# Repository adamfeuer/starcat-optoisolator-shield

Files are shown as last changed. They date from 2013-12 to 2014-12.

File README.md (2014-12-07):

StarCat Optoisolator Shield
===========================

This is an opto-isolated digital input/output shield for the Arduino Due.

It's good for low-noise synchronization of digital equipment (push-buttons, etc.) with 
an Arduino Due system. The optical isolation enables the connection of otherwise-noisy
external circuits or equipment, preventing ground or power supply noise from affecting 
sensitive ADC measurements. 

Meant for use with the [HackEEG](https://github.com/adamfeuer/hackeeg-shield) 24-bit EEG 
ADC board.

Features
========

* 4 opto-isolated inputs
* 2 opo-isolated outputs
* Screw terminals for connecting external inputs and outputs
* Uses Vishay [ILD213T](http://www.vishay.com/docs/83647/ild205t.pdf) optoisolator IC

License
=======

[Creative Commons By-Attribution ShareAlike 4.0](https://creativecommons.org/licenses/by-sa/4.0/)

Comments
========

If you have questions, comments, or improvements, I would love to know them!

cheers <br>
adam <br>
Adam Feuer <br>
Seattle, WA, USA <br>
adam@adamfeuer.com <br>
http://adamfeuer.com <br>

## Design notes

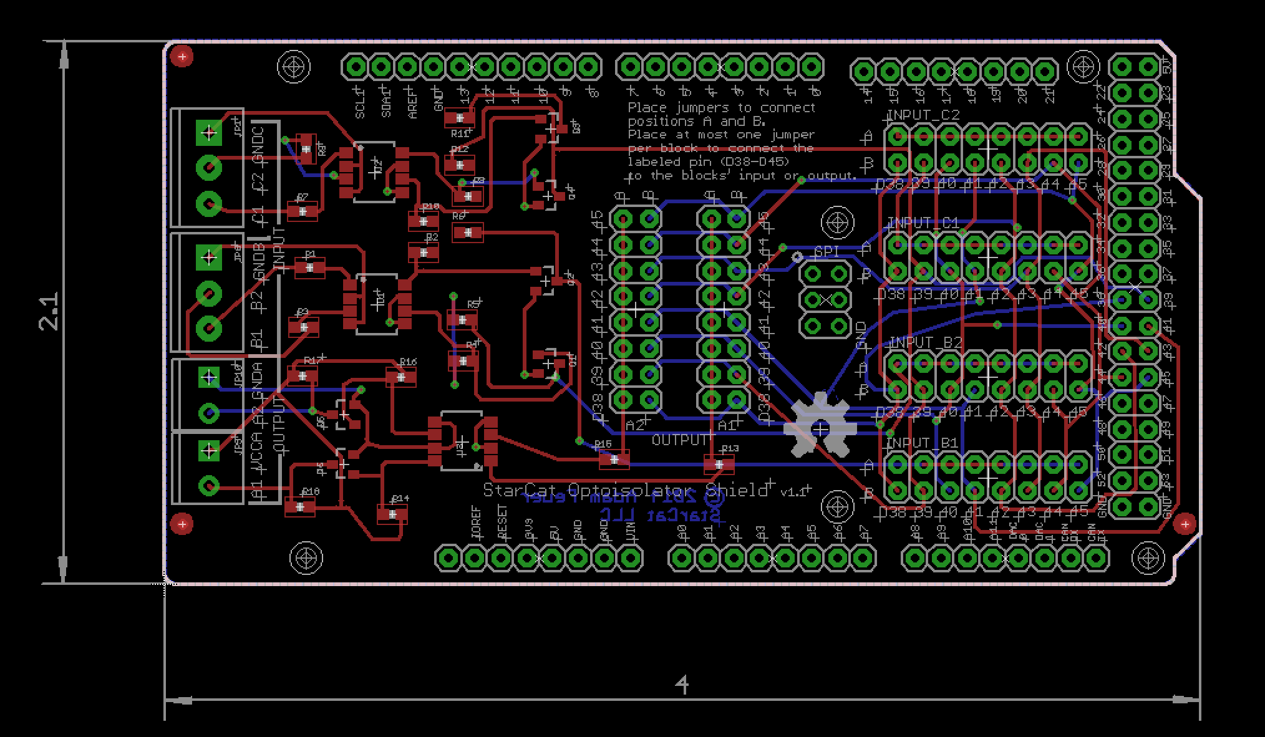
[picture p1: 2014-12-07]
optoisolator-shield.png

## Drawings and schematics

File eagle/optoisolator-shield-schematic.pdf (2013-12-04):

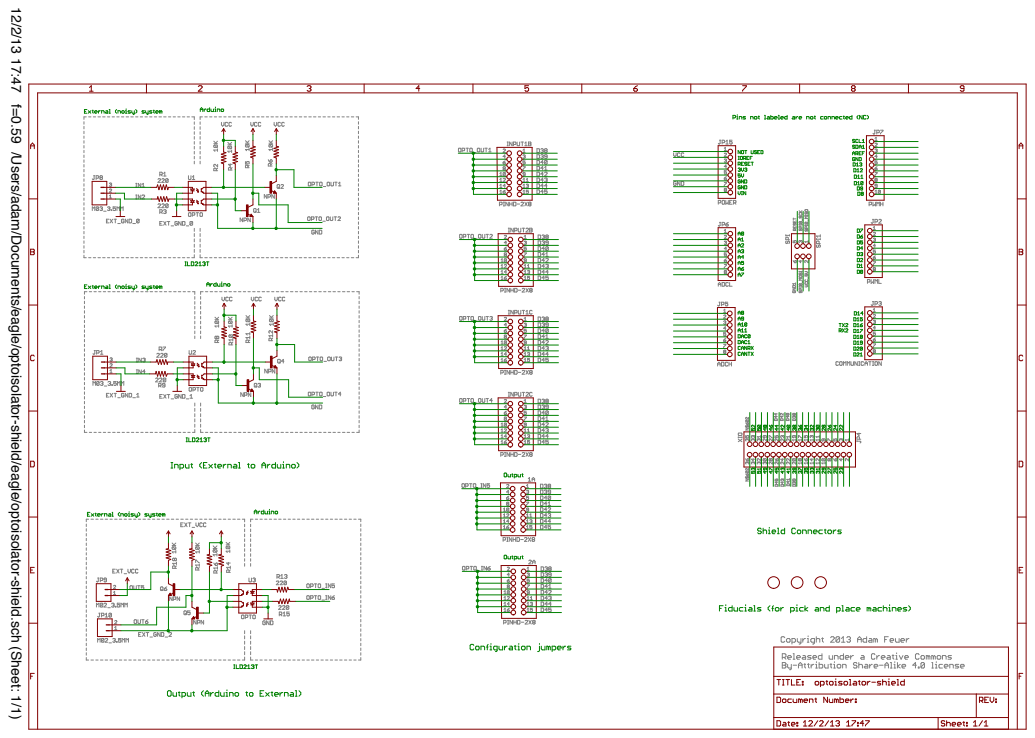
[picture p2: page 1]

12/2/13 17:47 f=0.59 /Users/adam/Documents/eagle/optoisolator-shield/eagle/optoisolator-shield.sch (Sheet: 1/1)

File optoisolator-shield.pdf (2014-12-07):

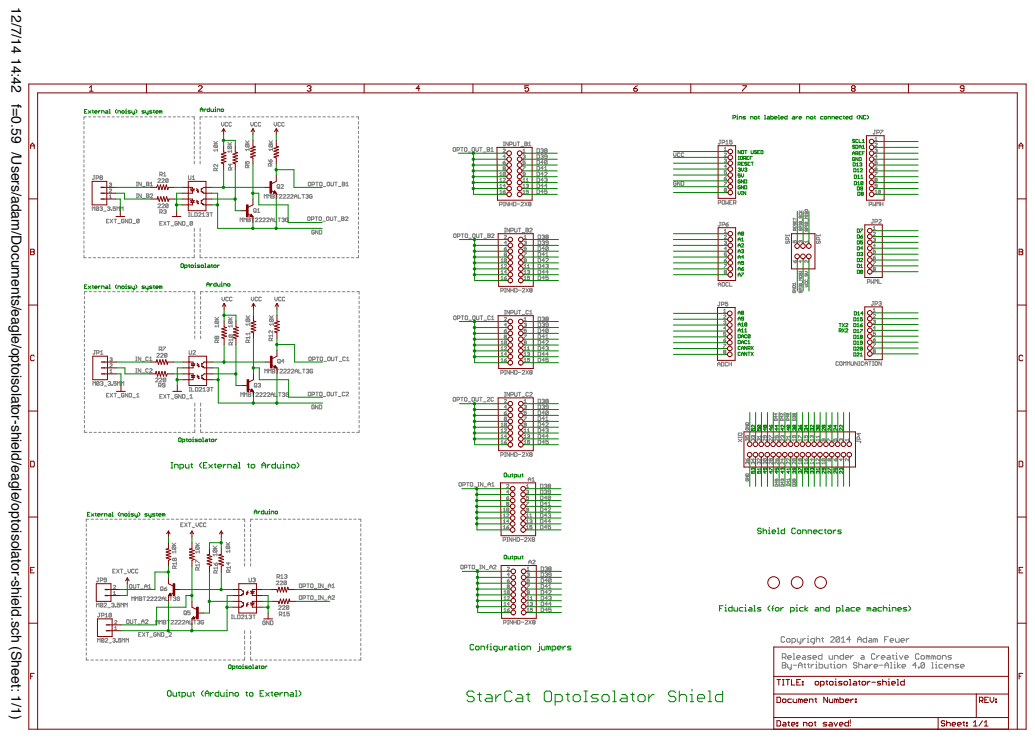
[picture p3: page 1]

12/7/14 14:42 f=0.59 /Users/adam/Documents/eagle/optoisolator-shield/eagle/optoisolator-shield.sch (Sheet: 1/1)

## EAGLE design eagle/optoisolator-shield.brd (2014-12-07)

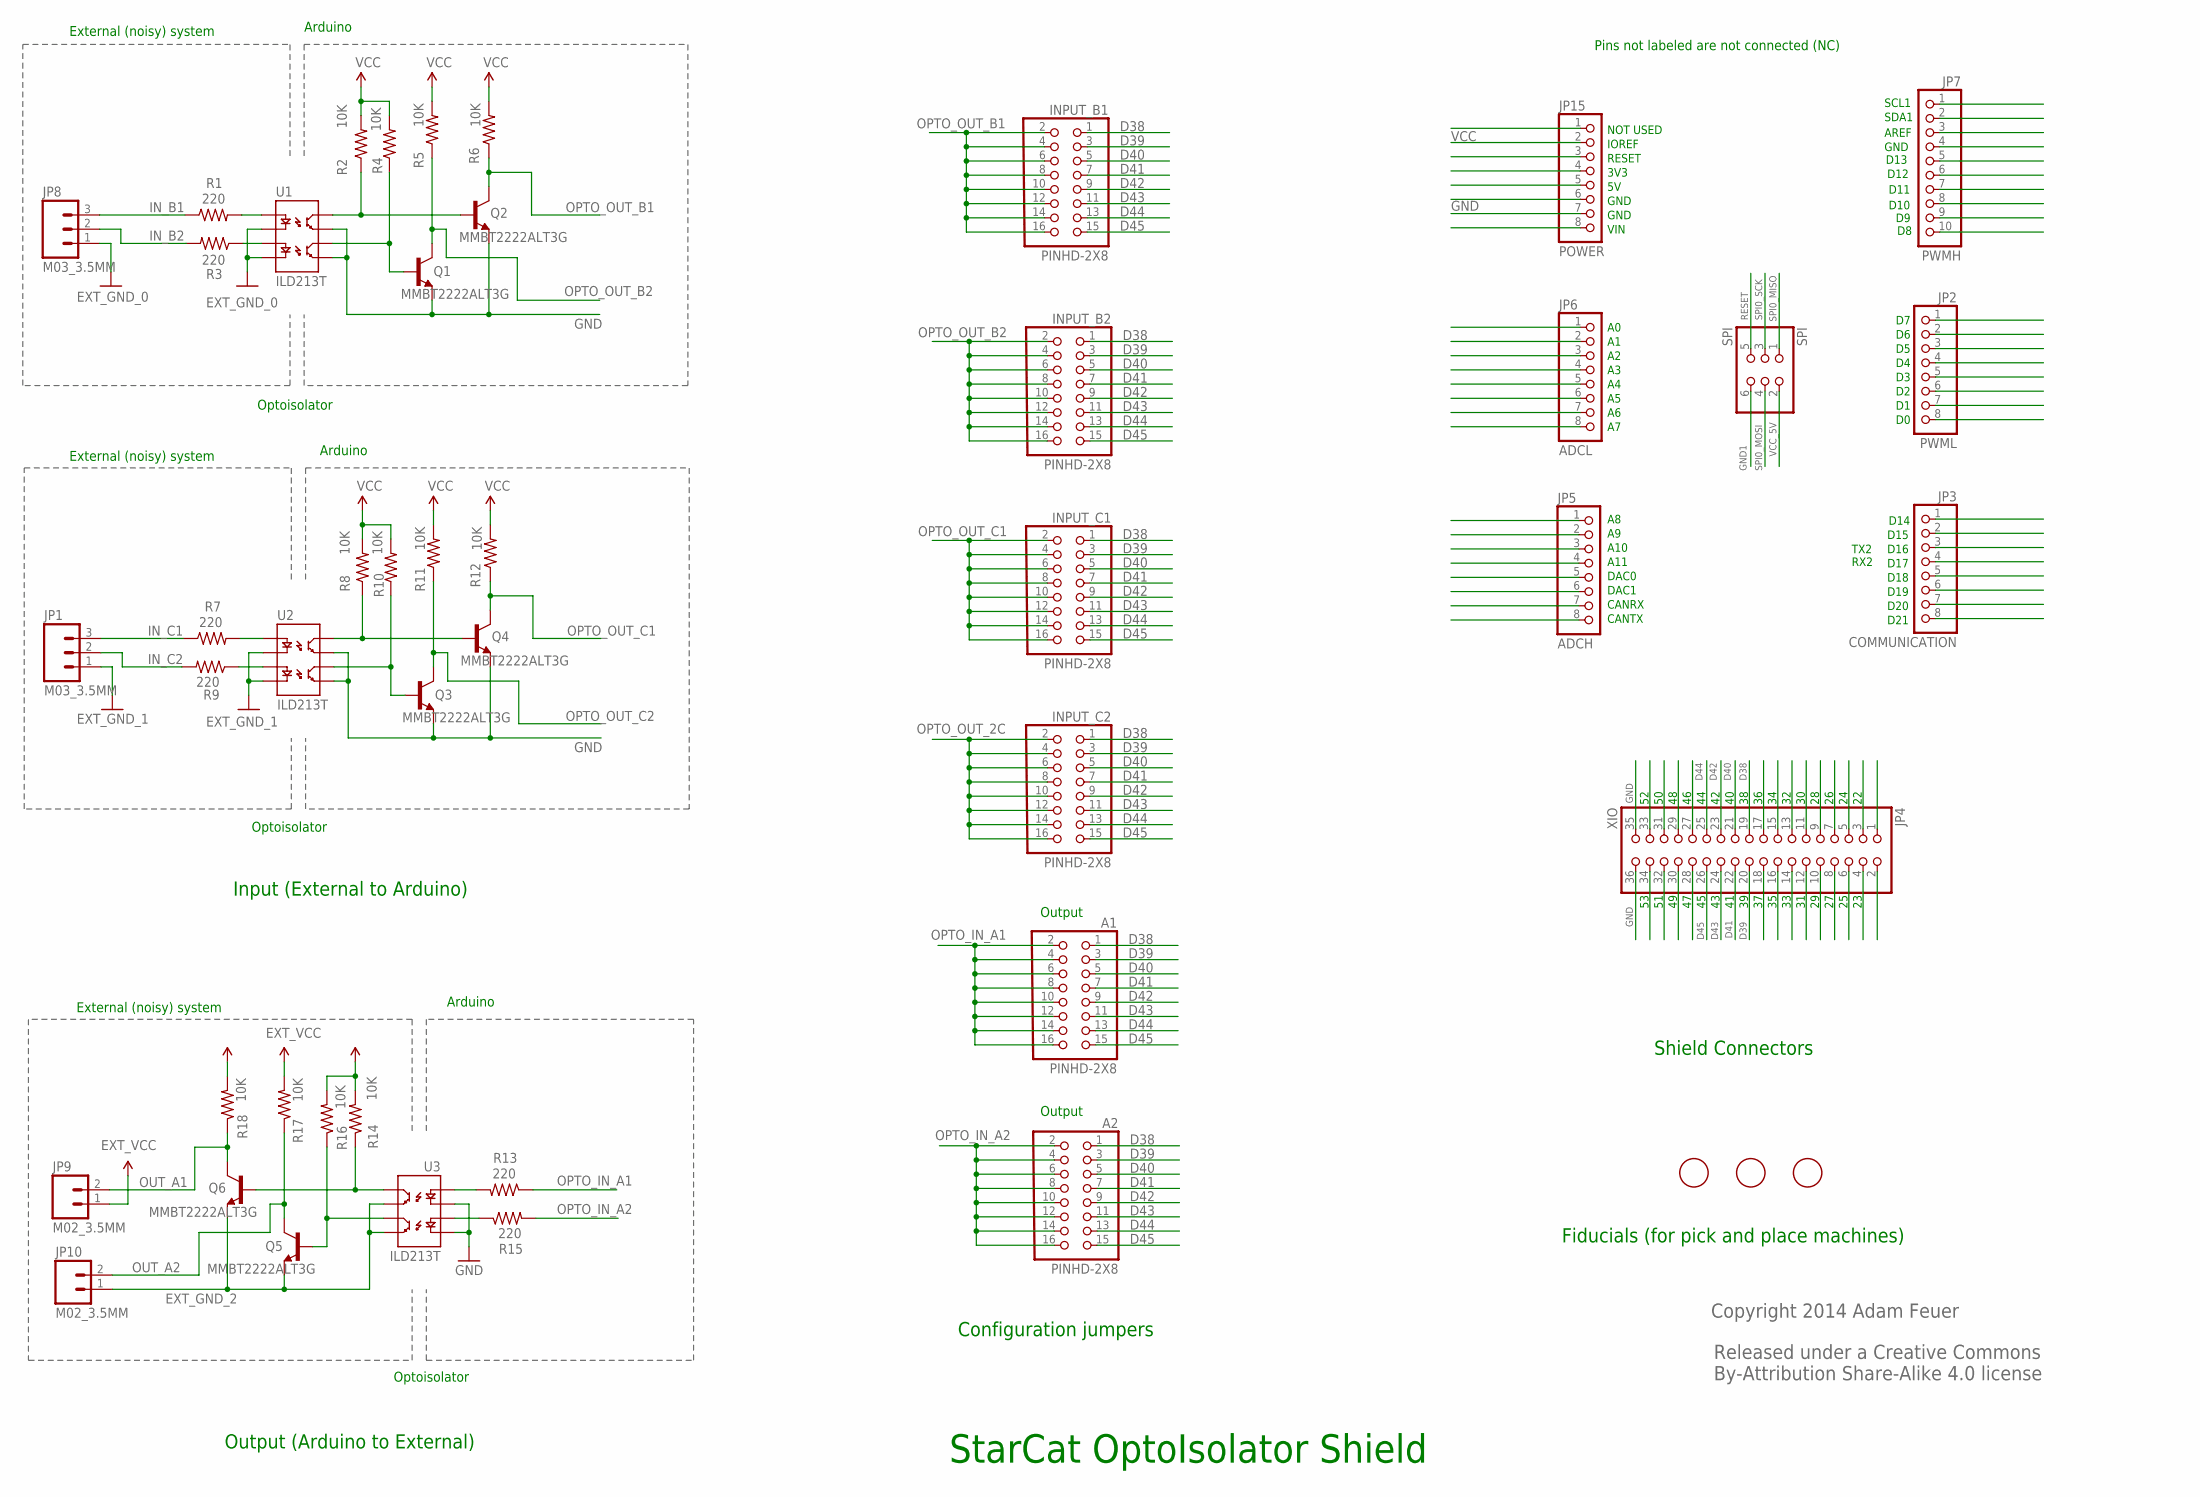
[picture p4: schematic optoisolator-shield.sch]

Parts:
A1, A2: PINHD-2X8; 2X08
INPUT_B1, INPUT_B2: PINHD-2X8; 2X08
INPUT_C1, INPUT_C2: PINHD-2X8; 2X08
JP1, JP8: M03_3.5MM; SCREWTERMINAL-3.5MM-3
JP2: PWML; 1X08
JP3: COMMUNICATION; 1X08
JP4: XIO; 2X18
JP5: ADCH; 1X08
JP6: ADCL; 1X08
JP7: PWMH; 1X10
JP9, JP10: M02_3.5MM; SCREWTERMINAL-3.5MM-2
JP15: POWER; 1X08
Q1, Q2, Q3, Q4, Q5, Q6: MMBT2222ALT3G; SOT23-3
R1, R3, R7, R9, R13, R15: 220; 0603-RES
R2, R4, R5, R6, R8, R10, R11, R12, R14, R16, R17, R18: 10K; 0603-RES
SPI: SPI; 2X03
U1, U2, U3: ILD213T; SO08-2
U$2, U$5, U$6: FIDUCIAL; FIDUCIAL_1MM

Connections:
D38: A1.1, A2.1, INPUT_B1.1, INPUT_B2.1, INPUT_C1.1, INPUT_C2.1, JP4.19
D39: A1.3, A2.3, INPUT_B1.3, INPUT_B2.3, INPUT_C1.3, INPUT_C2.3, JP4.20
D40: A1.5, A2.5, INPUT_B1.5, INPUT_B2.5, INPUT_C1.5, INPUT_C2.5, JP4.21
D41: A1.7, A2.7, INPUT_B1.7, INPUT_B2.7, INPUT_C1.7, INPUT_C2.7, JP4.22
D42: A1.9, A2.9, INPUT_B1.9, INPUT_B2.9, INPUT_C1.9, INPUT_C2.9, JP4.23
D43: A1.11, A2.11, INPUT_B1.11, INPUT_B2.11, INPUT_C1.11, INPUT_C2.11, JP4.24
D44: A1.13, A2.13, INPUT_B1.13, INPUT_B2.13, INPUT_C1.13, INPUT_C2.13, JP4.25
D45: A1.15, A2.15, INPUT_B1.15, INPUT_B2.15, INPUT_C1.15, INPUT_C2.15, JP4.26
EXT_GND_0: JP8.1, U1.2 (C1), U1.4 (C2)
EXT_GND_1: JP1.1, U2.2 (C1), U2.4 (C2)
EXT_GND_2: JP10.1, Q5.2 (E), Q6.2 (E), U3.5 (EM2), U3.7 (EM1)
EXT_VCC: JP9.1, R14.2, R16.2, R17.2, R18.2
GND: JP4.35, JP4.36, JP15.7, Q1.2 (E), Q2.2 (E), Q3.2 (E), Q4.2 (E), U1.5 (EM2), U1.7 (EM1), U2.5 (EM2), U2.7 (EM1), U3.2 (C1), U3.4 (C2)
GND1: SPI.6
IN_B1: JP8.3, R1.1
IN_B2: JP8.2, R3.2
IN_C1: JP1.3, R7.1
IN_C2: JP1.2, R9.2
unnamed: R1.2, U1.1 (A1)
unnamed: R3.1, U1.3 (A2)
unnamed: R7.2, U2.1 (A1)
unnamed: R9.1, U2.3 (A2)
unnamed: R13.2, U3.1 (A1)
unnamed: R15.1, U3.3 (A2)
OPTO_IN_A1: A1.2, A1.4, A1.6, A1.8, A1.10, A1.12, A1.14, A1.16, R13.1
OPTO_IN_A2: A2.2, A2.4, A2.6, A2.8, A2.10, A2.12, A2.14, A2.16, R15.2
OPTO_OUT_2C: INPUT_C2.2, INPUT_C2.4, INPUT_C2.6, INPUT_C2.8, INPUT_C2.10, INPUT_C2.12, INPUT_C2.14, INPUT_C2.16
OPTO_OUT_B1: INPUT_B1.2, INPUT_B1.4, INPUT_B1.6, INPUT_B1.8, INPUT_B1.10, INPUT_B1.12, INPUT_B1.14, INPUT_B1.16, Q2.3 (C), R6.1
OPTO_OUT_B2: INPUT_B2.2, INPUT_B2.4, INPUT_B2.6, INPUT_B2.8, INPUT_B2.10, INPUT_B2.12, INPUT_B2.14, INPUT_B2.16, Q1.3 (C), R5.1
OPTO_OUT_C1: INPUT_C1.2, INPUT_C1.4, INPUT_C1.6, INPUT_C1.8, INPUT_C1.10, INPUT_C1.12, INPUT_C1.14, INPUT_C1.16, Q4.3 (C), R12.1
OPTO_OUT_C2: Q3.3 (C), R11.1
OUT1N1: Q4.1 (B), R8.1, U2.8 (CL1)
OUT1N2: Q2.1 (B), R2.1, U1.8 (CL1)
OUT1N3: Q6.1 (B), R14.1, U3.8 (CL1)
OUT2N1: Q3.1 (B), R10.1, U2.6 (CL2)
OUT2N2: Q1.1 (B), R4.1, U1.6 (CL2)
OUT2N3: Q5.1 (B), R16.1, U3.6 (CL2)
OUT_A1: JP9.2, Q6.3 (C), R18.1
OUT_A2: JP10.2, Q5.3 (C), R17.1
RESET: SPI.5
SPI0_MISO: SPI.1
SPI0_MOSI: SPI.4
SPI0_SCK: SPI.3
VCC: JP15.2, R2.2, R4.2, R5.2, R6.2, R8.2, R10.2, R11.2, R12.2
VCC_5V: SPI.2

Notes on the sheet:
Configuration jumpers
Released under a Creative Commons By-Attribution Share-Alike 4.0 license
Copyright 2014 Adam Feuer
Shield Connectors
A10
A11
DAC0
DAC1
CANRX
CANTX
NOT USED
IOREF
RESET
3V3
GND
VIN
Fiducials (for pick and place machines)
Pins not labeled are not connected (NC)
Optoisolator
SCL1
SDA1
AREF
D13
D12
D11
D10
D14
D15
D16
D17
D18
D19
D20
D21
TX2
RX2
Arduino
External (noisy) system
Input (External to Arduino)
Output (Arduino to External)

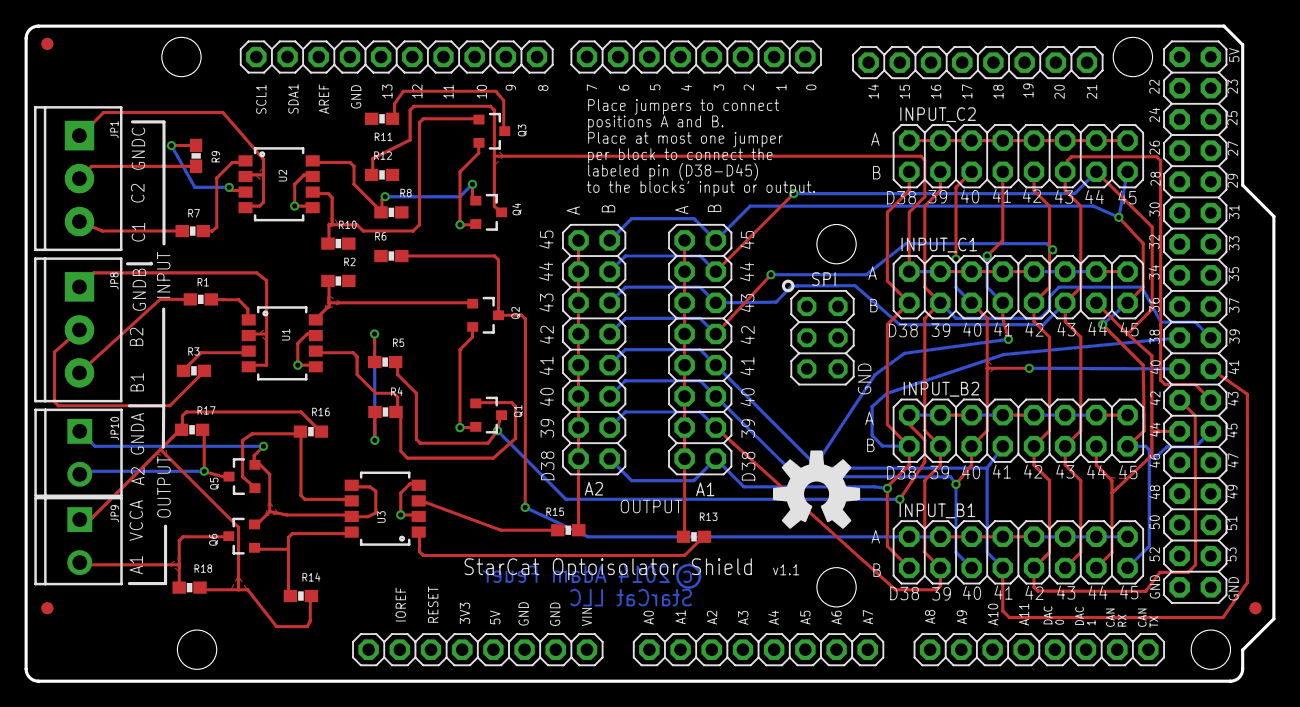
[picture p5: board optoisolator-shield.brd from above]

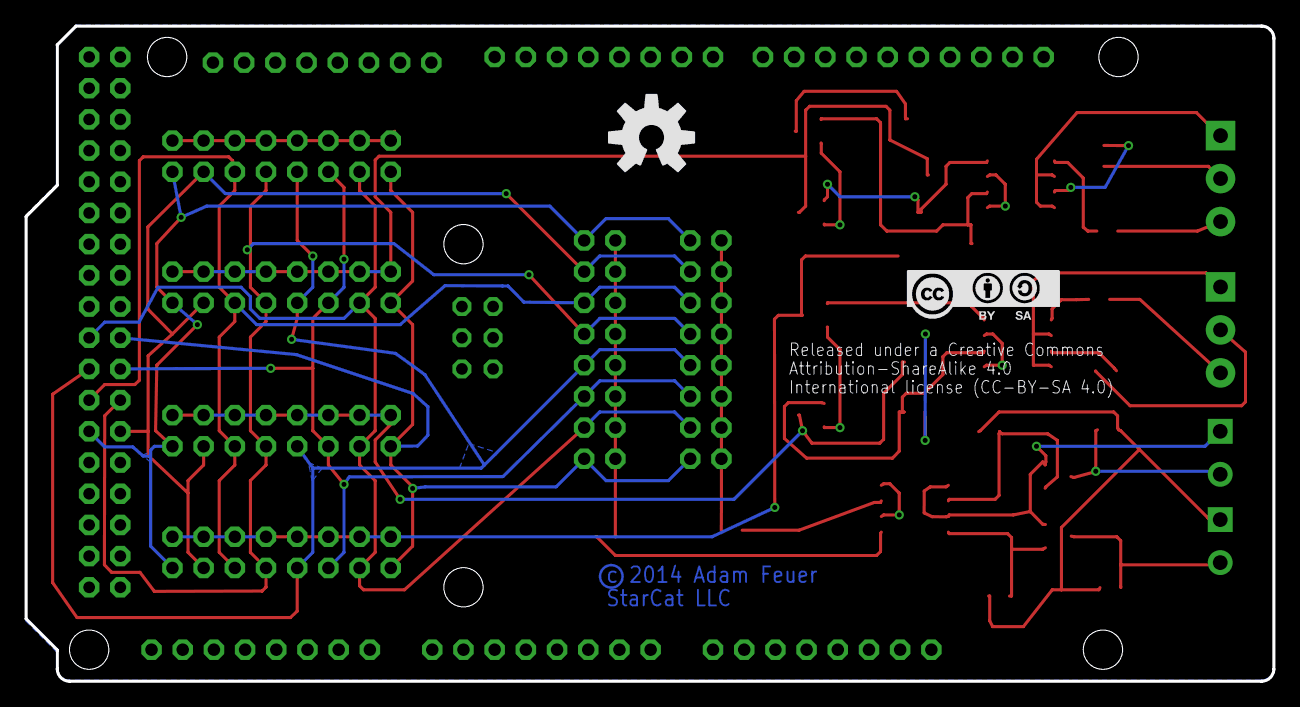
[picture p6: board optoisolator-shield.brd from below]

Board: 2 copper layers, 101.6 x 53.3 mm, 51 parts (2 on the bottom side), 39 nets.

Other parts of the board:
U$1, U$3: OSHW-LOGO-L
U$4: CC-BY-SA

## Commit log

2013-11-29 initial addition
    [optocoupler-shield.brd, optocoupler-shield.sch]
2013-11-29 added optoisolators and config jumpers; jumpers are all connected to shield IO pins
    [optocoupler-shield.brd, optocoupler-shield.sch]
2013-11-29 renamed shield files to match project name
    [optoisolator-shield.brd, optoisolator-shield.sch]
2013-12-01 fixed direction of optoisolators; added an output to go along with the 2 inputs; all components are still SMT
    [optoisolator-shield.brd, optoisolator-shield.sch]
2013-12-02 added cam and util directories; routed board, touch-ups still in progress
    [optoisolator-shield.brd, optoisolator-shield.sch]
2013-12-03 updated board silkscreen to include instructions
    [optoisolator-shield.brd, optoisolator-shield.sch]
2013-12-03 updated signal names for optoisolator in/out to match the board silkscreen labels
    [optoisolator-shield.brd, optoisolator-shield.sch]
2013-12-04 corrected board outline positioning to make origin at 0,0; added creative-commons logo library
    [optoisolator-shield.brd]
2013-12-04 added schematic pdf
2013-12-04 improved some trace clearances by rerouting them
    [optoisolator-shield.brd]
2013-12-04 improved some trace clearances
    [optoisolator-shield.brd]
2014-01-13 fixed XIO orientation error propagated from HackEEG shield
    [optoisolator-shield.brd, optoisolator-shield.sch]
2014-01-22 updated silkscreen with correct dac0/1 and canrx/tx labels; updated fiducials so 2 share the same X and 2 share the same Y coordinates
    [optoisolator-shield.brd, optoisolator-shield.sch]
2014-02-04 improved trace clearances; changed names of inputs from 1A... to A1... for better readability
    [optoisolator-shield.brd, optoisolator-shield.sch]
2014-02-04 updated schematic renaming inputs/outputs 1A... to A1... for clarity
    [optoisolator-shield.brd, optoisolator-shield.sch]
2014-02-04 improved trace clearance and copper pour
    [optoisolator-shield.brd]
2014-12-07 added README, schematic, and PCB picture
2014-12-07 added shield name to schematic
    [optoisolator-shield.brd, optoisolator-shield.sch]
2014-12-07 rotating schematic PDF to be correct orientation

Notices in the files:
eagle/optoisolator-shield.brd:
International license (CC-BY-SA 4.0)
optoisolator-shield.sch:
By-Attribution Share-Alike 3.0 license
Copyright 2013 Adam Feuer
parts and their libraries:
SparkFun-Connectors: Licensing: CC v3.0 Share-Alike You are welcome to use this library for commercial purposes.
